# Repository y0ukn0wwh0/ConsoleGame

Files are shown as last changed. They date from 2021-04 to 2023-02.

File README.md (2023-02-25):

# Portable Gaming Console

This repository contains the development process of a portable gaming console based on Arduino, as well as 'DUNG!', a game made with the Arduboy library.
The following paragraphs detail the steps to the building of the console, the game installation and a brief description of it.

## Console Assembly

The following components are used:
- Arduino Nano
- 3 PTS636 switches, 2.5mm height
- MSK12C01-07 slide switch
- 601730 battery, 250mAh, 6*17*30mm dimensions
- TP4056 charging module
- 5kΩ SMD resistor
- i2c OLED screen, 0.96 inches, with the ssd1306 chip
- 5V buzzer, 12mm diameter
- 2 headers, 15 pins each (Arduino Nano)
- Our custom PCB (you can download the files [here](/Console/pcb_dev.zip) and upload them to EasyEDA)

Before welding the components to the PCB it is necessary to switch the charging module resisor to the 5kΩ one.

Having acquired all the required components one can procees with their welding to the PCB following the [schematic](/Console/schematic.png). The following welding order is advised:
1. Charging module
2. Bottom header
3. Buzzer
4. Screen
5. Sliding switch
6. Top header
7. 3 switches
8. Battery



With all the components in place, the board can be set in the box.

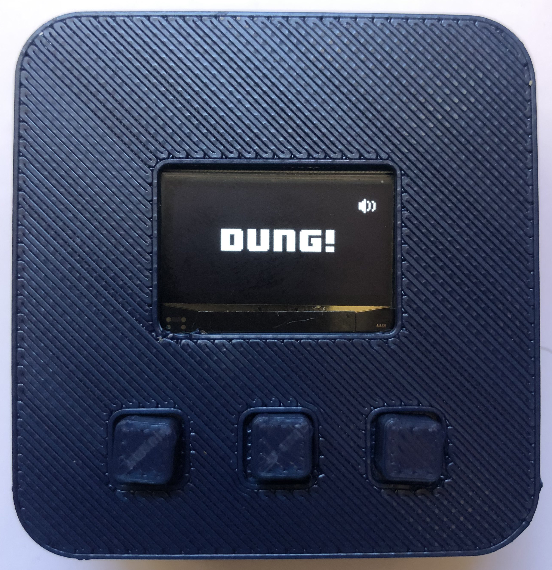
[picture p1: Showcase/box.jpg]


## Alternative to the PCB welding
If one wants a simple setup, the assembly can be done on a breadboard. In this case the only components needed are the Arduino, switches, screen and buzzer. These can be connected to the Arduino pins following the image:

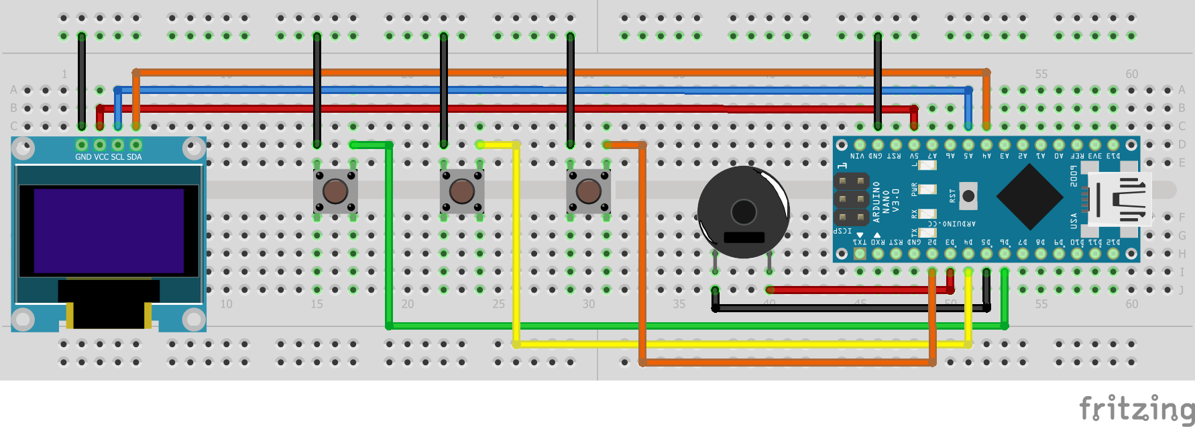
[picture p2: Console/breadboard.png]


## Game
To install the game, the libraries available in the ... folder are necessary. These were obtained from the following repositories:
- [Arduboy2](https://github.com/MLXXXp/Arduboy2)
- [ArduboyTones](https://github.com/MLXXXp/ArduboyTones)
- [ArdBitmap](https://github.com/igvina/ArdBitmap)

The versions available in this repository were slightly altered due to some needed changes like the modification of the button pins.

These libraries are then placed in the correct directory so that the Arduino IDE imports them (generally 'C:\Program Files (x86)\Arduino\libraries').
After this you can simply upload the [game.ino](/Game/game/game.ino) file to the Arduino with the [sprites.c](/Game/game/sprites.c) file in the same folder. The installation is now complete.

### Mechanics
The game has various rounds each containing various levels. The number of levels in each round is increased as the player progresses. The objective is simply to complete as most levels as you can.

In each level, enemies launch projectiles in the direction of the player. In turn, the player has to reflect them by pressing the corresponding button in the right rythm.
Beyond the enemies getting stronger as the game moves forward, at the final level of each round a boss enemy shows up, making the progression more difficult.

At the beginning of each attempt, the following characters are offered as a choice to the player:
| | Warrior | Archer  | Mage |
| --- | --- | --- | --- |
| **Health** | 6 | 4 | 2 |
| **Attack** | 2 | 3 | 4 |

By successfully reflecting enemy projectiles the player wins 'special points'. After accumulating 6 of these points, the player can use the character's special ability:
- **Warrior**: Creates a shield that blocks an enemy projectile.
- **Archer**: Shoots an arrow that drags enemy projectiles in it's direction. In case it hits an enemy directly it inflicts twice the damage.
- **Mage**: Shoots a projectile that heals 1 health point if it hits an enemy. If it doesn't, the mage is unable to attack for 2 seconds. 

There are also various items given to the player randomly after a finished round. These items can be:
- **Weapons**: Add attack damage to the player. Weapons give more damage depending on their level.
- **Gems**: There are several types of gems and they duplicate the damage the player inflicts if they correspond to the type of enemy.
- **Potions**: Heals 1 health point when used.
The player can only hold two items but they can be switched if another one is found. Note that the item that is switched out is lost.

The following image showcases the different bosses correpondent to the enemy/gem types in this order:
- Swamp
- Undead
- Ancient
- Fire
- Forest
- Normal


### Controls
The console's three buttons have the following functions:
| | A Button | B Button | C Button |
| --- | --- | --- | --- |
| **Menus** | Move to the left | Select/Confirm | Move to the right/Return |
| **Game**  | Reflect projectiles | Use potion | Use special attack |

### Interface
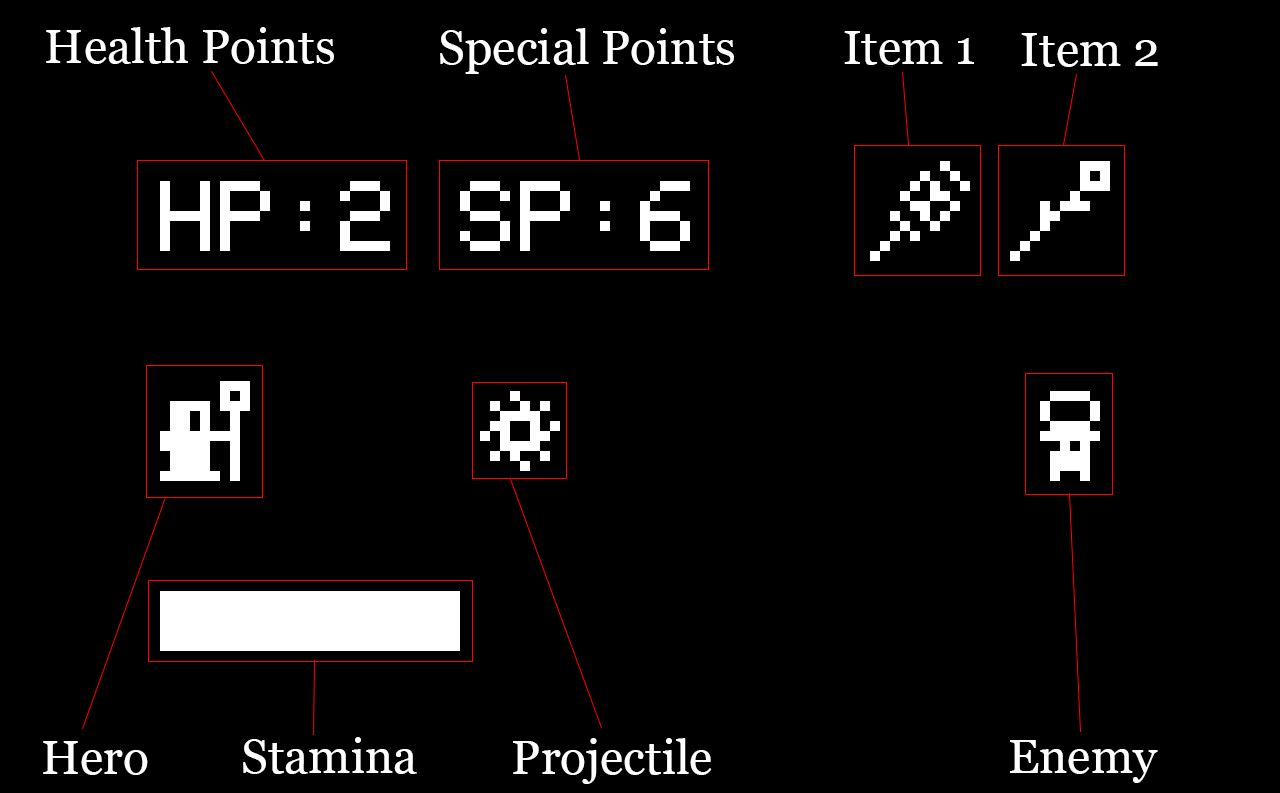
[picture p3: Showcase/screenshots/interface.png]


### Screens
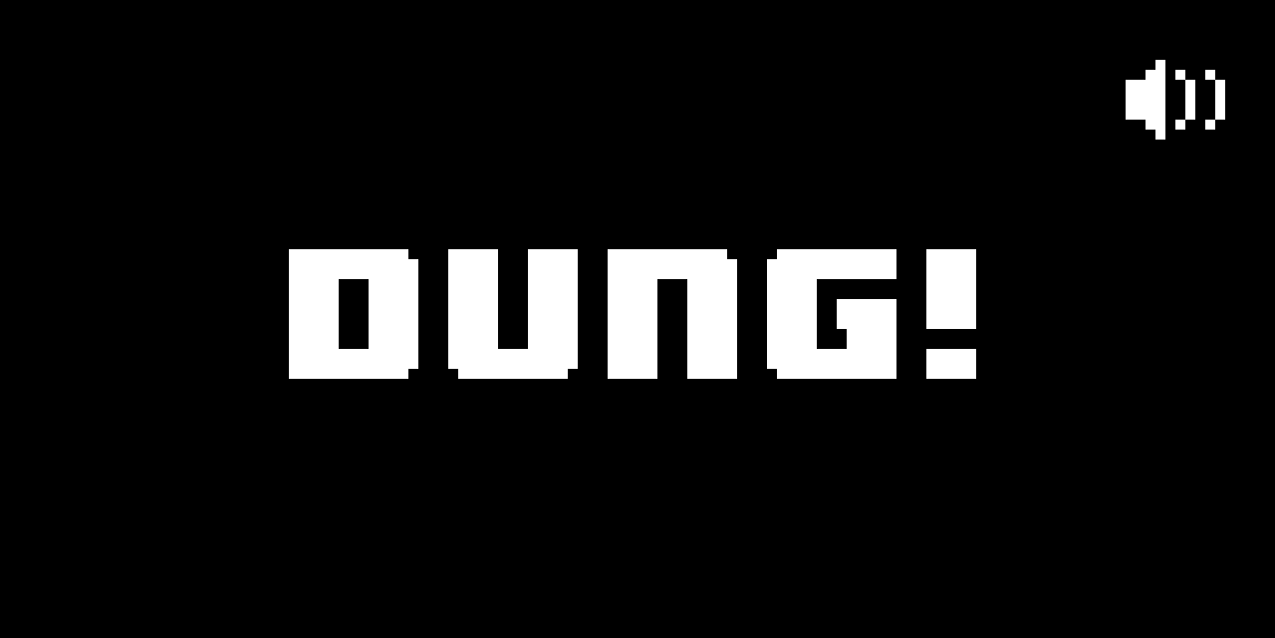
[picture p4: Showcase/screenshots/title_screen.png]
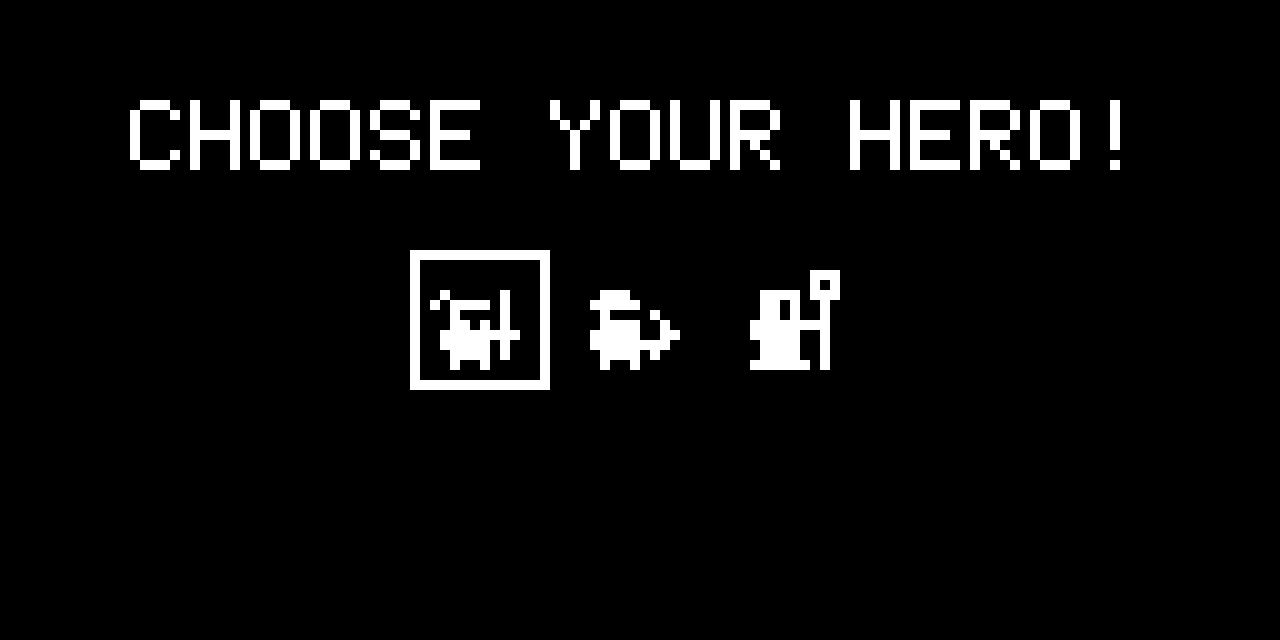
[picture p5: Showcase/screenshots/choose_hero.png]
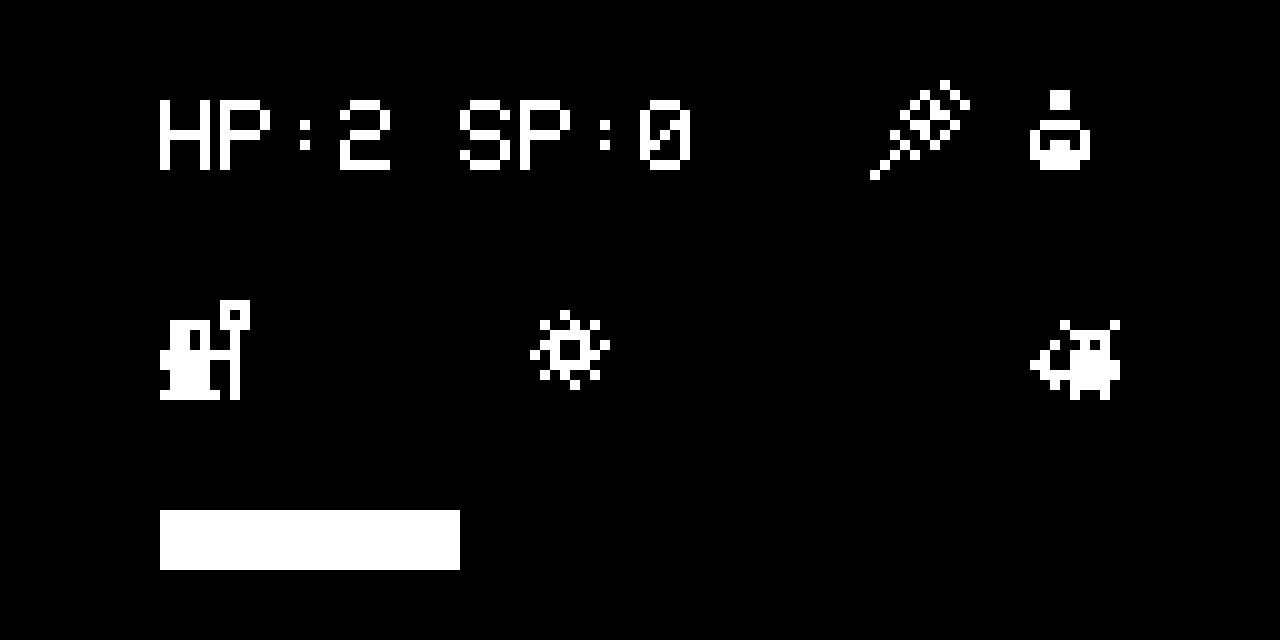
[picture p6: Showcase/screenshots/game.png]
    
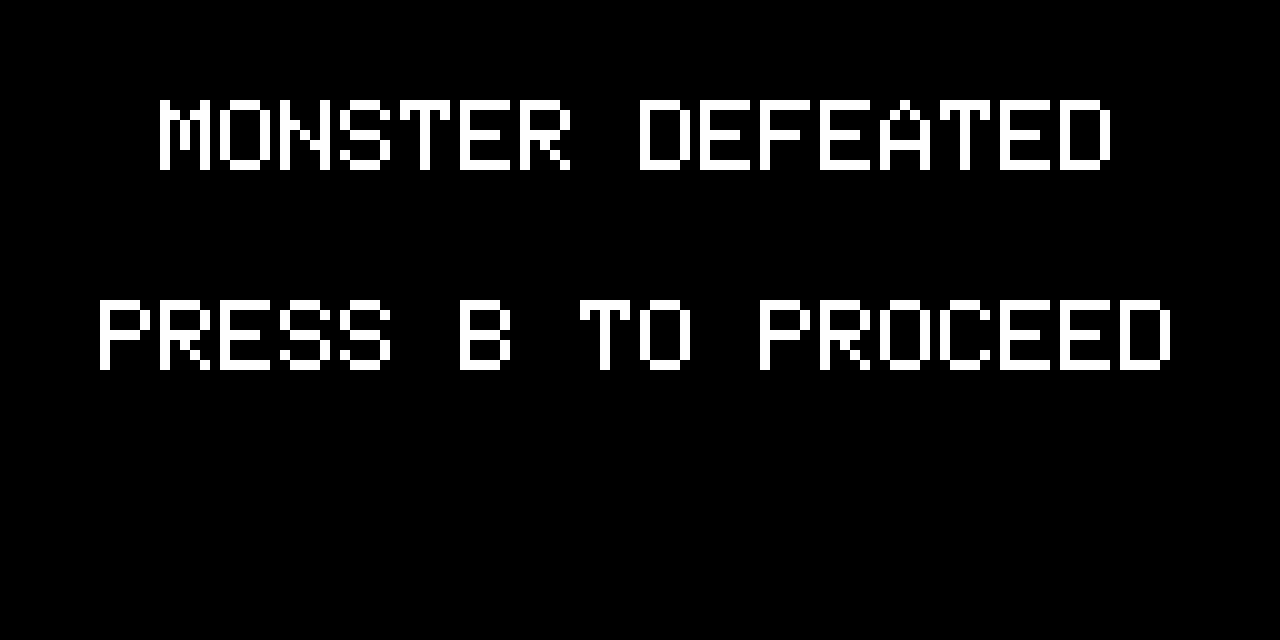
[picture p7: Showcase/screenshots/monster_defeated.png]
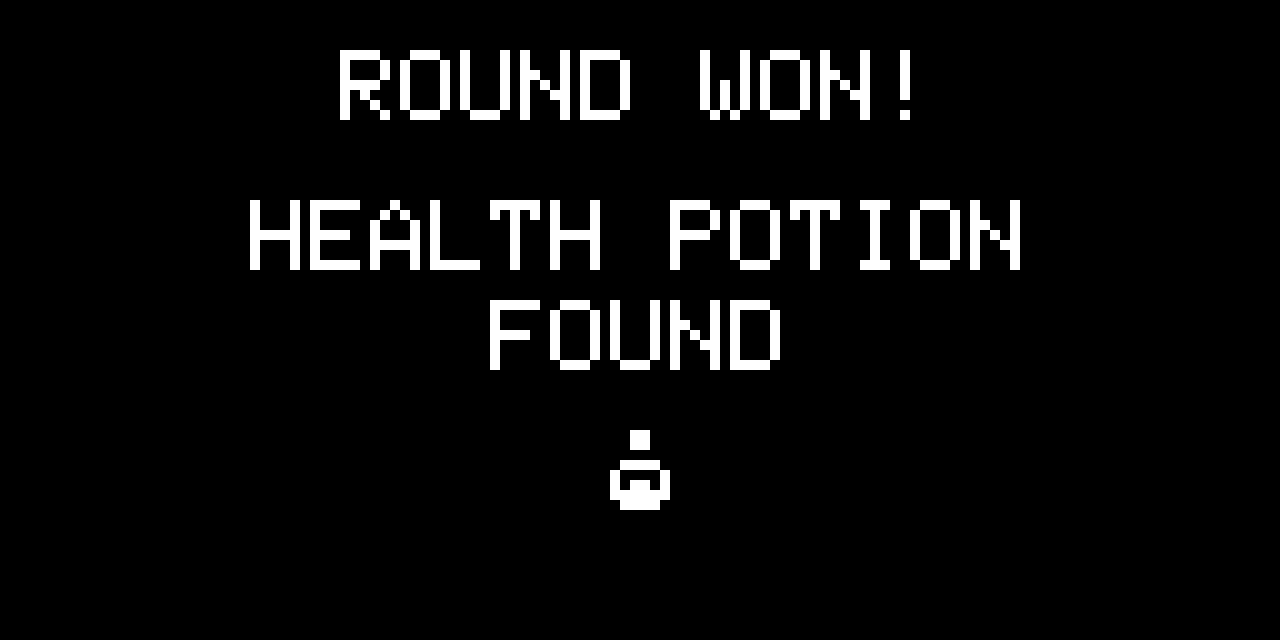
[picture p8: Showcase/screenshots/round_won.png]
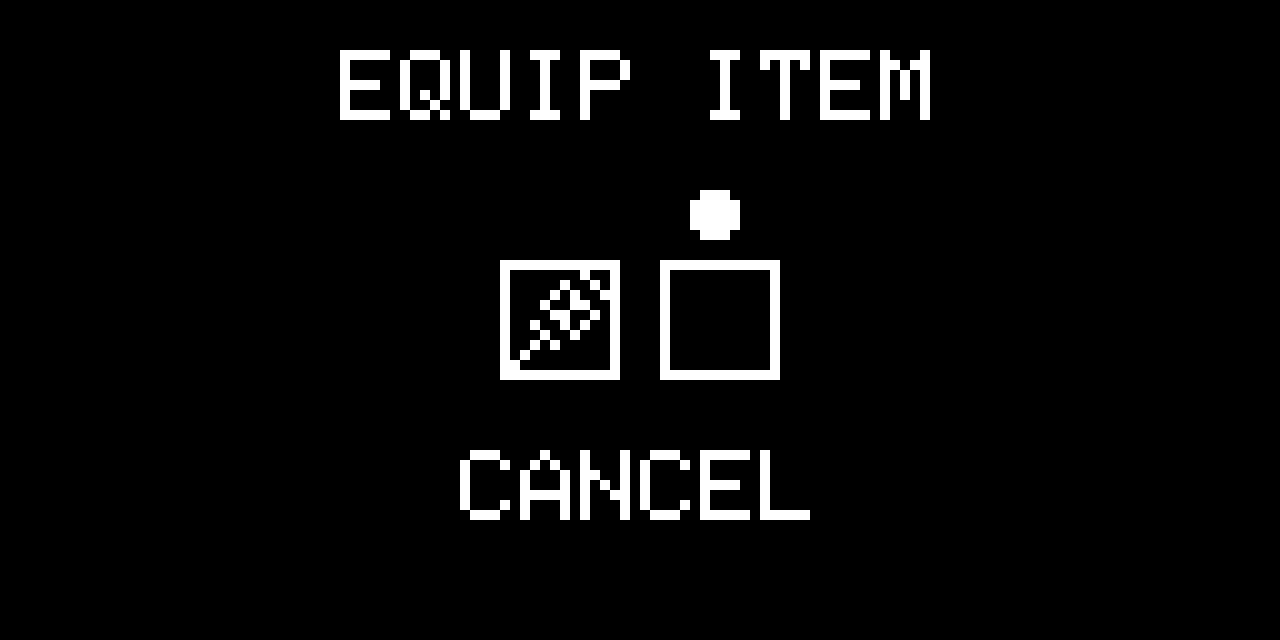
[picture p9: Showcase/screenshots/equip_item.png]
    
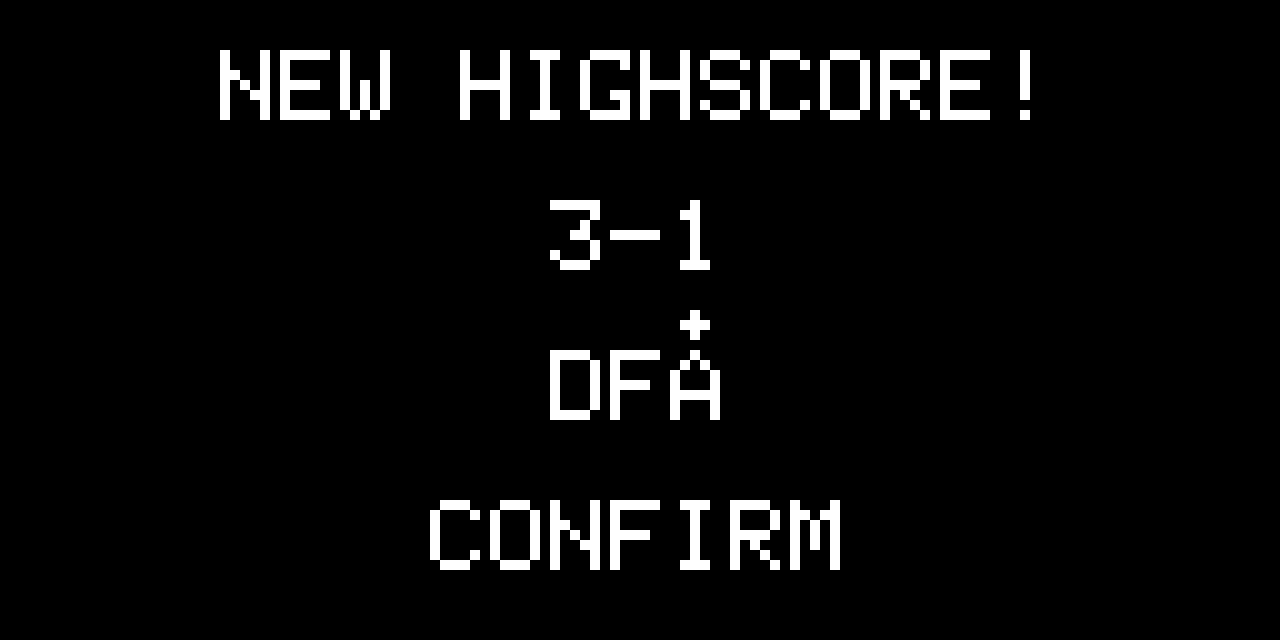
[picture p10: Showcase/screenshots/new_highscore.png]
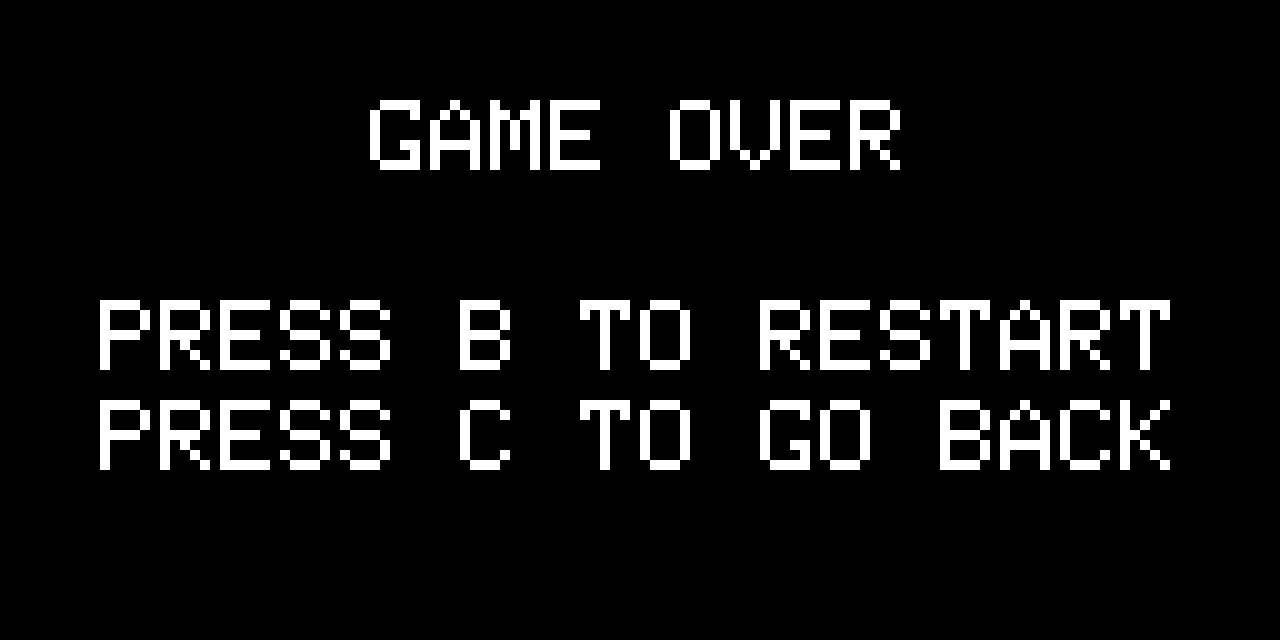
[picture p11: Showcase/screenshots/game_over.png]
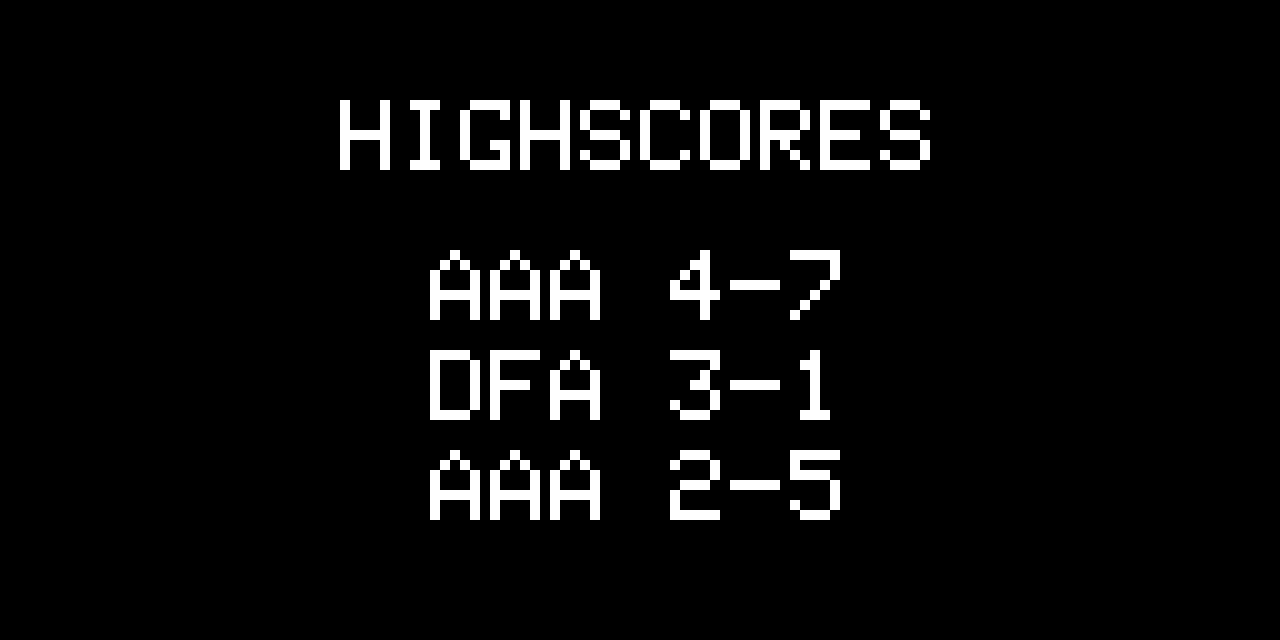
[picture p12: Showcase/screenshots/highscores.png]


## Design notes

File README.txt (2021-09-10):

## Consola de jogo portátil

Este repositório contem o processo de desenvlvimento de uma consola portátil baseada em Arduino, assim como um jogo feito com a biblioteca Arduboy, o DUNG!.
A seguir estão os passos para a construção da mesma assim como a instalação do jogo.

### Consola

São usados os seguintes componentes:
- Arduino Nano
- 3 interruptores PTS636 de 2.5mm de altura
- Interruptor deslizante MSK12C01-07
- Bateria 601730 de 250mAh com dimensões 6*17*30mm
- Módulo de carregamento TP4056
- Resistência SMD de 5kΩ 
- Ecrã OLED i2c de 0.96 polegadas com o chip ssd1306
- Buzzer de 5V, 12mm de diâmetro
- 2 headers cada um com capacidade para 15 pinos (do Arduino Nano)
- O nosso PCB

Antes de se soldar os componentes ao PCB é necessário trocar a resistência do módulo de carregamento para a desejada de 5kΩ.

Tendo todos os componentes prontos é feita agora a soldagem dos mesmos ao PCB. Foi seguida a seguinte ordem de soldagem:
1. Módulo de carregamento
2. Header de baixo
3. Buzzer
4. Ecrã
5. Interruptor deslizante
6. Header de cima
7. 3 interruptores
8. Bateria

A placa fica então com o seguinte aspeto:

Assim a placa eletrónica pode agora ser inserida na caixa desenhada para a consola. Sendo este o resultado final:

### Jogo
Para a instalação do jogo são necessárias as bibliotecas disponíveis na pasta 03_Implementacao. Estas foram obtidas dos seguintes repositórios:
- [Arduboy2](https://github.com/MLXXXp/Arduboy2)
- [ArduboyTones](https://github.com/MLXXXp/ArduboyTones)
- [ArdBitmap](https://github.com/igvina/ArdBitmap)
As versões aqui disponíveis estão ligeiramente diferentes devido a algumas mudanças necessárias como a alteração dos pinos dos botões.

As bibliotecas são então postas na respetiva diretoria para que o Arduino IDE as importe (geralmente C:\Program Files (x86)\Arduino\libraries).
Após isto basta fazer upload do ficheiro game.ino com o ficheiro sprites.c (na pasta 03_Implementacao) para o Arduino. Fica assim a instalção completa.

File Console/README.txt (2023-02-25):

This folder holds the schematics of the eletronic circuit and the pcb as well as the breadboard assembly. The pcb development files exported from EasyEDA are also here inside the 'pcb_dev.zip' file.
In the 'console box' folder are all the files of the box design made in SolidWorks, along with a PNG image showcasing the box model.

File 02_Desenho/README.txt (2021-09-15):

Nesta pasta está o documento de design do jogo desenvolvido em paralelo com o projeto.
Estão também as esquemáticas do circuito, do pcb e montagem numa breadboard.
Na pasta 'caixa' estão todos os ficheiros de desenho da caixa desenvolvidos no SolidWorks, assim como uma imagem PNG.

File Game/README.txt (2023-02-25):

The 'Arduino' folder contains the libraries used in the game development with our changes made.
The 'game' folder contains the main game files:
	- 'game.ino' is the main code with the game mechanics.
	- The file 'sprites.c' has all the graphics used in the game in 'bitmap' format.
	- The python file 'arduboy_screen.py' is used to mirror the game to a computer screen. This was mostly used to take screenshots.

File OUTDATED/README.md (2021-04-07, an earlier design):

# Project

Our goal is to create an arduino-powered mini console that plays a virtual pet game, also developed by the team.
In this current phase of development we have established the following thematics:
- PCB main board developed by the team, to give the console a shape and to connect the following components:

	- Arduino Nano;
	- 0.96" OLED screen;
	- 6 buttons;
	- Buzzer;
	- TP4056 micro-usb lithium battery charging module;
	- 90mAh LiPo battery;
	- RC-522 RFID module;

- Develop the pet's statistics by doing either idle actions or interacting with the pet through minigames;

	- Feeding minigame, where the player has to control his pet to catch food falling from the top of the screen;
	- Exercise minigame, where the player has to hit a sequence of keys presented to him, in it's exact order;
	- Adventure minigame, where the pet goes on an adventure and the console is set idle, until the pet comes back;

- RFID implementation (sensor and tag) to randomize events or let players fight which eachother's pets;

The concepts presented here are still rough ideas, they can and will be changed in the future, to match the team's ideas.

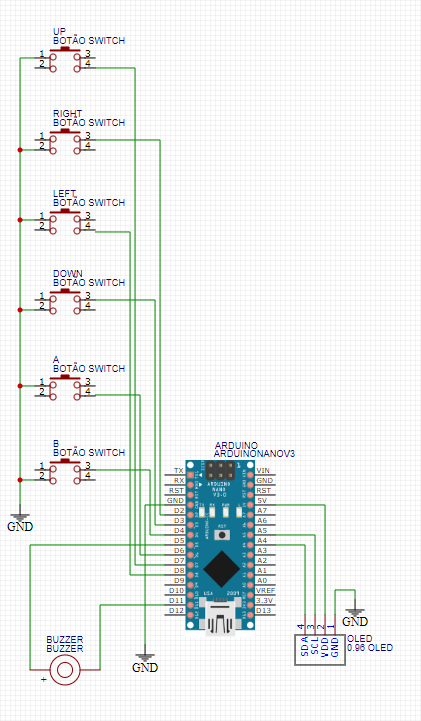
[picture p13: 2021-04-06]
images/schematic.png

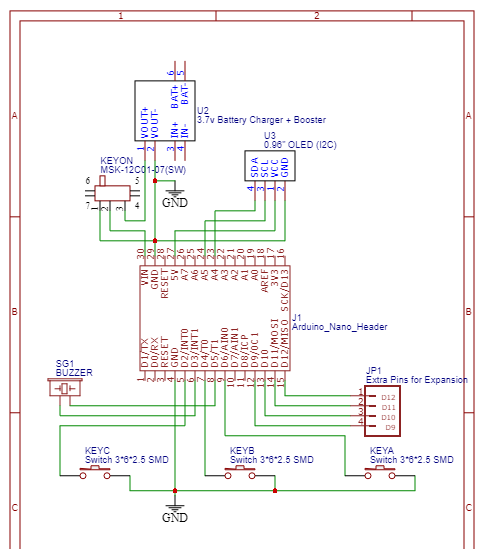
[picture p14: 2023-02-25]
Console/schematic.png

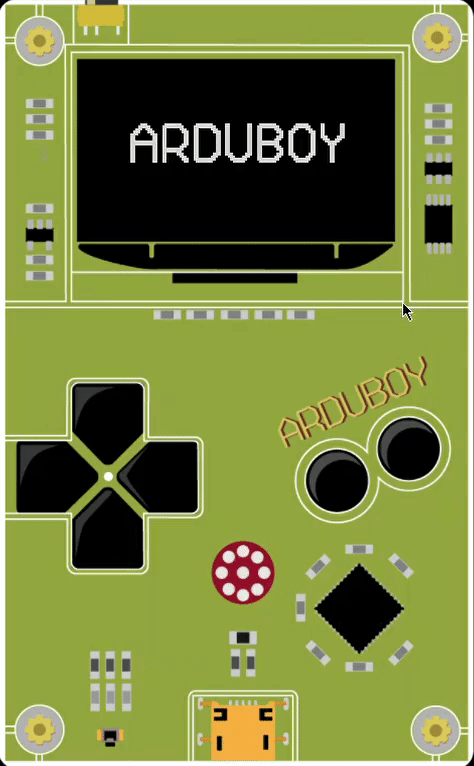
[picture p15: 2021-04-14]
images/match.gif

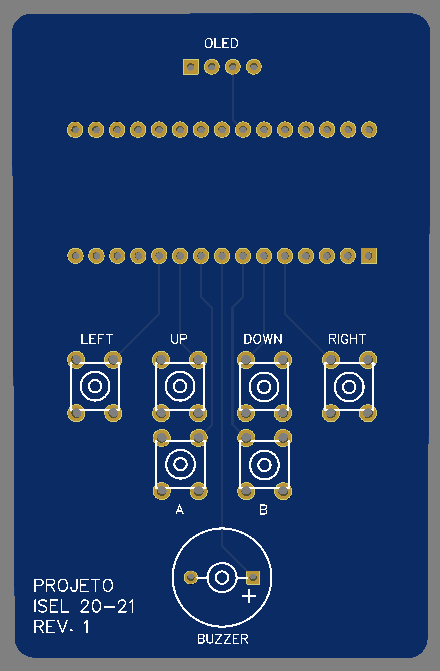
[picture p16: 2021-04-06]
images/pcb_3d_front.png

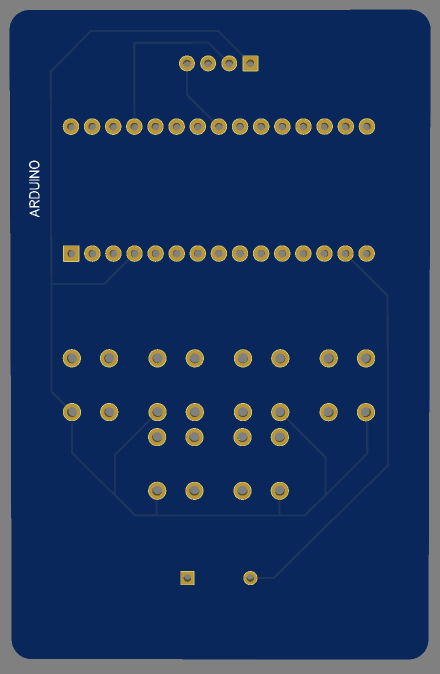
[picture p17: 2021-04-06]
images/pcb_3d_back.png

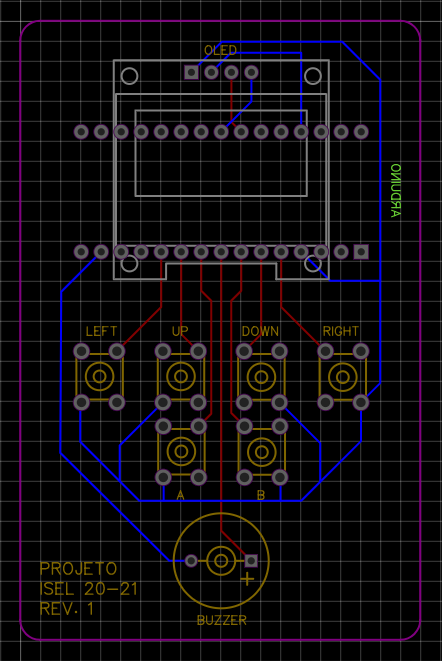
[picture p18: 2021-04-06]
images/pcb.png

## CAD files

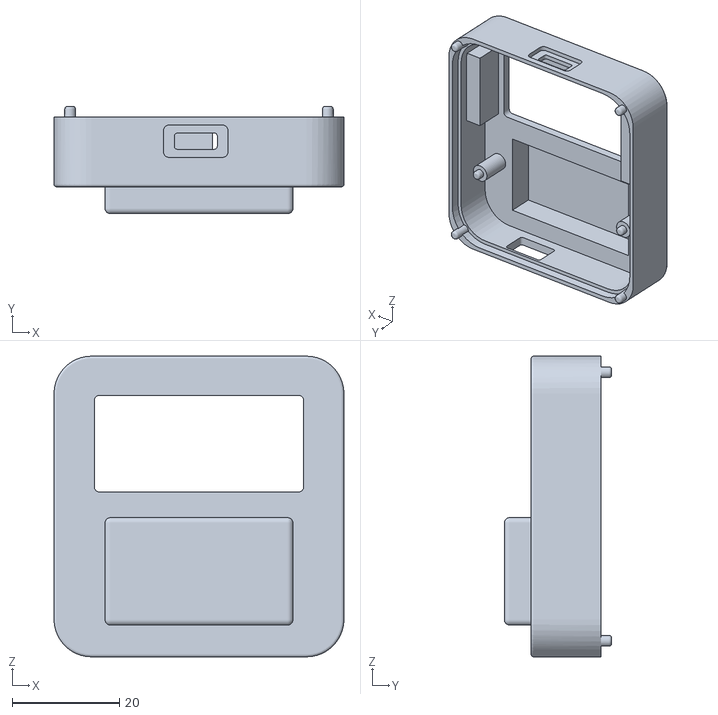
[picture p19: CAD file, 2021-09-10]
Console/console box/AssemblyV2 - PartBottom-2.STL
54.0 x 20.0 x 56.0

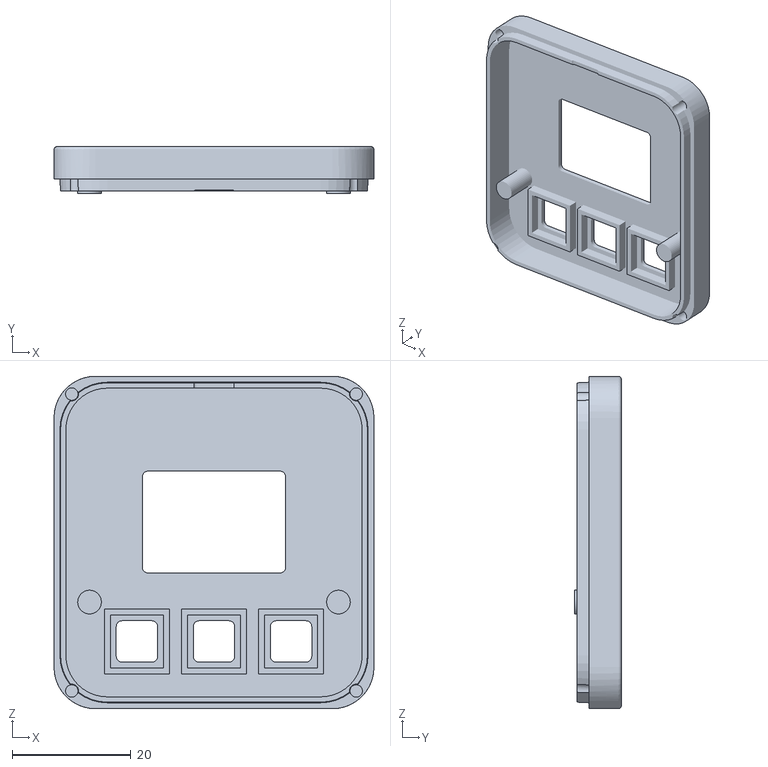
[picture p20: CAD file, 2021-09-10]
Console/console box/AssemblyV2 - PartTop-1.STL
54.0 x 7.90 x 56.1

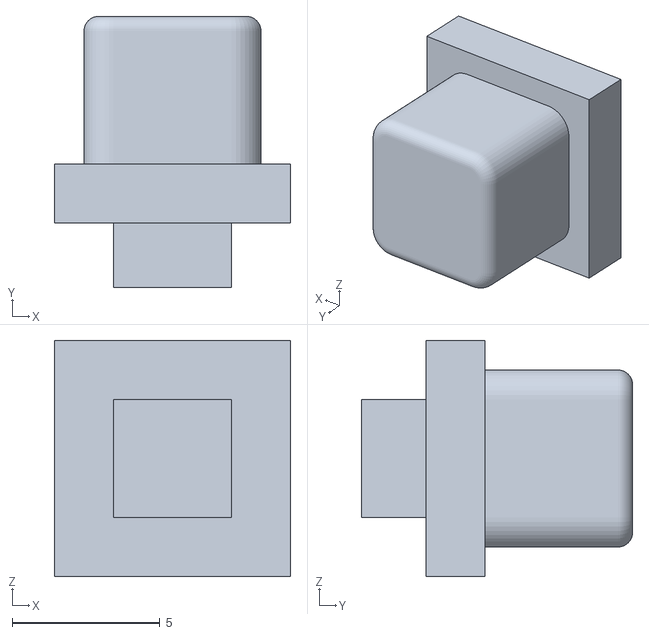
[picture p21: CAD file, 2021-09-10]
Console/console box/AssemblyV2 - Button-1.STL
8.00 x 9.20 x 8.00

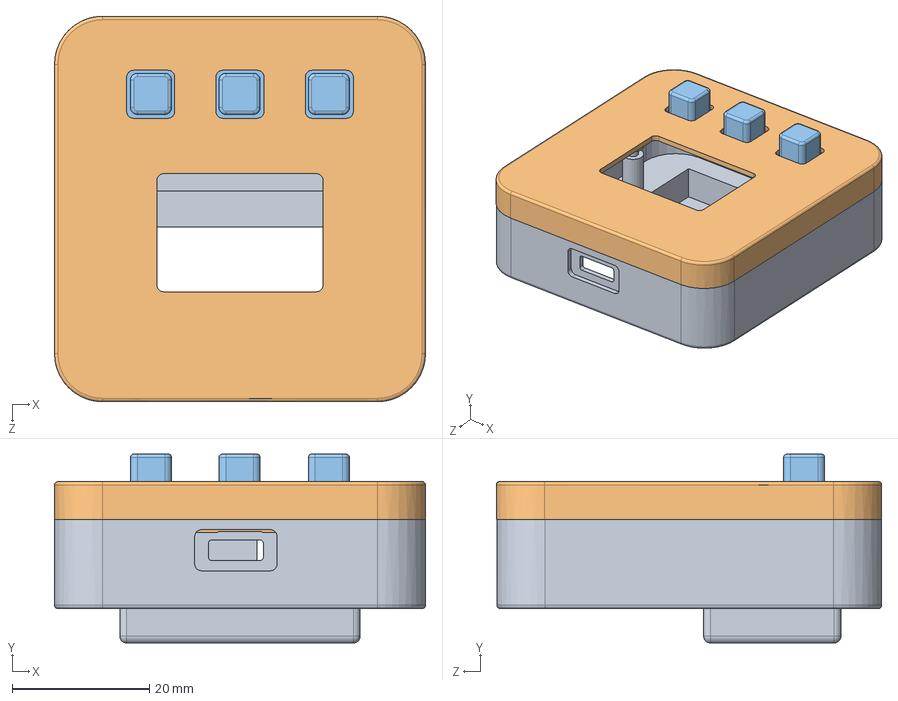
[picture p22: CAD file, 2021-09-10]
Console/console box/Assembly.SLDASM
54.0 x 27.5 x 56.1 mm
PartBottom
PartTop
Button x 3

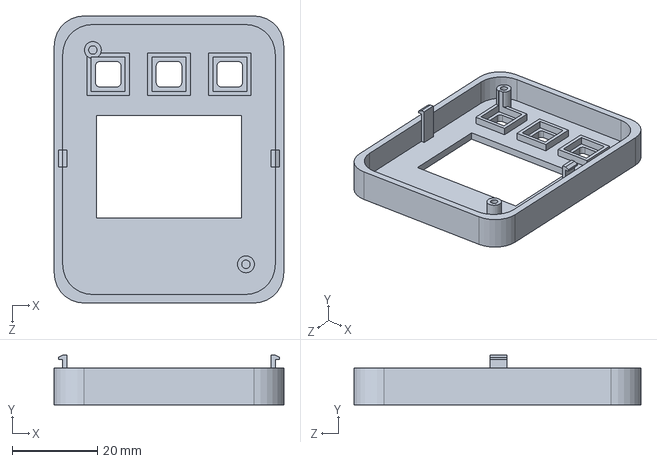
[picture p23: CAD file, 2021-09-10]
Console/console box/PartTop.SLDPRT
54.0 x 11.7 x 67.5 mm

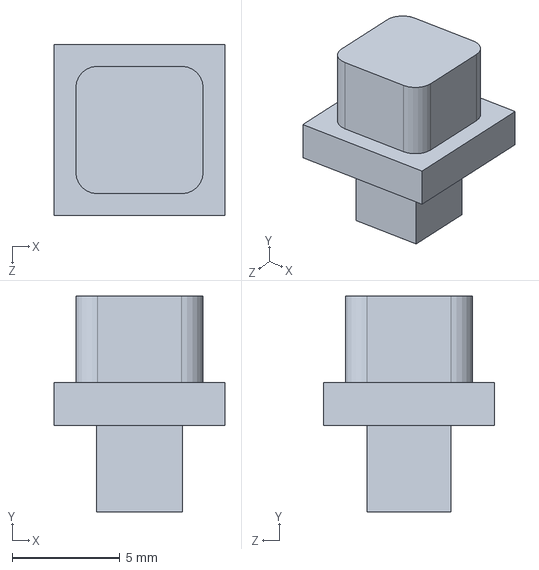
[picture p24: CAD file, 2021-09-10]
Console/console box/Button.SLDPRT
7.90 x 10.0 x 7.90 mm

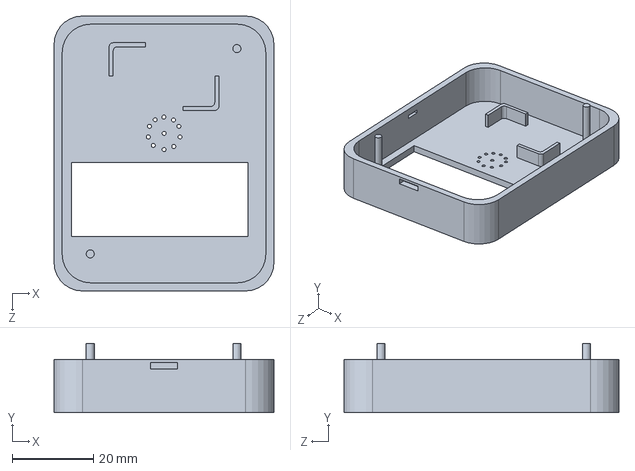
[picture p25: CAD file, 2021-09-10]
Console/console box/PartBottom.SLDPRT
54.0 x 17.0 x 67.5 mm

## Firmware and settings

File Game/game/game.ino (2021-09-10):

#include <Arduboy2.h>
#include <ArduboyTones.h>
#include <EEPROM.h>
#include "sprites.c"

const uint16_t score[] PROGMEM = {
 NOTE_C5,205, NOTE_REST,205, NOTE_C5,205, NOTE_G5,205, NOTE_F5,205, NOTE_REST,205, NOTE_E5,205, NOTE_REST,205,
 NOTE_C5,205, NOTE_REST,205, NOTE_C5,205, NOTE_G5,205, NOTE_F5,205, NOTE_REST,205, NOTE_E5,205, NOTE_REST,205,
 NOTE_C5,205, NOTE_REST,1027, NOTE_E5,205, NOTE_REST,205, NOTE_C5,205, NOTE_REST,1027, NOTE_E5,205, NOTE_REST,205,
 TONES_REPEAT
};

#define HEROX 16                                                    //Hero position
#define FLOOR_LEVEL 40                                              //The bottom edge of where the heroes and monsters are drawn
#define BASIC_ENEMY_LEFT arduboy.width()-26                         //Left side of the basic enemies aka where the projectiles are spawned
#define BOSS_LEFT arduboy.width()-36                                //Left side of the bosses
#define REQUIRED_STAMINA 30                                         //The stamina the hero requires to attack       
#define REQUIRED_SPECIAL_POINTS 6                                   //Required special points to use hero's special 
#define REQUIRED_RECOVER_TIME 2000                                  //Time for the mage to recover from a failed spell
#define FIRST_ITEM_X arduboy.width()/2 - 9                          //X position of the first slot in the equip menu
#define SECOND_ITEM_X arduboy.width()/2 + 7                         //X position of the second slot in the equip menu
const String alphabet = "ABCDEFGHIJKLMNOPQRSTUVXYZ";                //Alphabet to insert the player's name when he has a new highscore

Arduboy2 arduboy;
ArduboyTones sound(arduboy.audio.enabled);
enum screen {start, choose, game, over, won, roundOver, equipItem, highscore}; //All the different screens in the game
screen sc = start;                                                  //Current screen
enum heroType {s, a, m};                                            //Types of heroes - Swordsman, Archer, Mage
byte heroChoiceX = 41;                                              //Used to determine where the selection rectangle in the choice menu is drawn
byte level, gameRound;                                              //Game level and round
uint8_t *enemy;                                                     //Enemy to draw
float projectileX, projectileSpeed;                                 //Enemy projectile's position and it's speed
bool goToPlayer;                                                    //Used to know whether the projectile goes towards the player
unsigned long projectileRecharge;                                   //Used to know when to spawn another projectile if needed
unsigned long recoverTime;                                          //Used to know if the recover time for the mage has passed after missing a spell
byte currentStamina;                                                //Current amount of stamina that the player has
byte maxEnemyHealth, enemyHealth;                                   //Enemies max and current health
byte enemyType;                                                     //Enemy type (1-Normal, 2-Forest, 3-Fire, 4-Swamp, 5-Ancient, 6-Undead)
byte enemyLeft;                                                     //Left side of the enemy, whter it be basic or boss
bool bossLevel, bossDefeated;                                       //Used to know if the level is a boss one and if it was defeated
uint8_t* rewardedItem;                                              //Rewarded item after a boss
String rewardName;                                                  //Rewarded item's name
bool itemFound;                                                     //Used to know if an item was found after the boss round
byte itemChoiceX = FIRST_ITEM_X;                                    //Used in the equip item screen to cyle through the item slots
byte letter1=0, letter2=0, letter3=0;                               //Letters of the name to register after a highscore. These are indexes of the alphabet string
byte letterChoiceX = arduboy.width()/2 - 7;                         //Used to cycle through the letters in the highscore screen
byte highscoreAddr;                                                 //EEPROM address to right a new highscore
bool showHighscore;                                                 //Tells the start screen to show the highscores or not
bool playAudio = true;                                              //Should the console play audio or not

//Animation stuff
#define ARDBITMAP_SBUF arduboy.getBuffer()                          //Screen buffer pointer expression (used in the ArdBitmap library)
#include <ArdBitmap.h>                                              //ArdBitmap - Library to edit sprites
ArdBitmap<WIDTH, HEIGHT> ardbitmap;
byte frame;                                                         //Used to draw the projectiles in the drawRotatedProjectile function
long changeFrameTime;                                               //Know when to change the frame
float logoSize;                                                     //Used in the resize animation for the logo in the start screen

//Used to know when is time to write the screen buffer to serial.
//unsigned long timeSerial;

//Hero classes
class Hero{
  public:
    byte maxHealth, health, basicAttack, attack, arrowX, spellX, specialPoints;
    uint8_t* weapon1; uint8_t* weapon2; uint8_t* weapon3; uint8_t* weapon4; uint8_t* weapon5;
    uint8_t* item1; uint8_t* item2;
    boolean usedSpecial = false, item1Def = false, item2Def = false;
    virtual void draw();
    virtual void useSpecial();
    virtual heroType getType();
};

//The Swordsman has a large amount of health, but does less damage 
//His special is a shield that protects him from the enemy one time
class Swordsman : public Hero{
  public:
    Swordsman(){
      maxHealth = 6; health = maxHealth; basicAttack = 2; attack = basicAttack;
      weapon1 = sword1; weapon2 = sword2; weapon3 = sword3; weapon4 = sword4; weapon5 = sword5;
    }
    virtual void draw(){
      arduboy.drawBitmap(HEROX,FLOOR_LEVEL-10, swordsman, 10, 10);
      if(usedSpecial)
        arduboy.drawCircle(HEROX+4, FLOOR_LEVEL-5, 7);
    }

    virtual void useSpecial(){
       if(!usedSpecial && specialPoints == REQUIRED_SPECIAL_POINTS){
        usedSpecial = true;
        specialPoints = 0;
      }
    }

    virtual heroType getType(){
      return s;
    }
};

//The Archer is has a decent amount of health and does a bit more damage than the Swordsman
//His special is an arrow that drags the enemy projectiles towards them but deals more damage if it doesn't
class Archer : public Hero{
  public:
    Archer(){
      maxHealth = 4; health = maxHealth; basicAttack = 3; attack = basicAttack;
      weapon1 = bow1; weapon2 = bow2; weapon3 = bow3; weapon4 = bow4; weapon5 = bow5;
    }
    virtual void draw(){
      arduboy.drawBitmap(HEROX,FLOOR_LEVEL-10, archer, 10, 10);
      if(usedSpecial){
        arduboy.drawBitmap(arrowX,FLOOR_LEVEL-5, arrow, 10, 3);
        arrowX+=2;

        //If arrow directly hits the enemy it does double the damage
        if(arrowX+10 >= enemyLeft){
          usedSpecial = false;
          arrowX = 0;
          (attack*2 > enemyHealth) ? enemyHealth = 0 : enemyHealth -= attack*2;
          if(playAudio)sound.tone(600,200);
        }
      }
    }
    virtual void useSpecial(){
      if(!usedSpecial && specialPoints == REQUIRED_SPECIAL_POINTS){
        arrowX = HEROX;
        usedSpecial = true;
        specialPoints = 0;
      }
    }
    virtual heroType getType(){
      return a;
    }
};

//The Mage is very fragile but does more damage than the other classes
//His special fires a spell that recovers 1 health point if it hits the enemy
//If it hits a projectile, it prevents the mage from doing anything for 2 seconds
class Mage : public Hero{
  public:
    Mage(){
      maxHealth = 2; health = maxHealth; basicAttack = 4; attack = basicAttack;
      weapon1 = staff1; weapon2 = staff2; weapon3 = staff3; weapon4 = staff4; weapon5 = staff5;
    }
    virtual void draw(){
      arduboy.drawBitmap(HEROX,FLOOR_LEVEL-10, mage, 10, 10);
      if(usedSpecial){
        arduboy.drawBitmap(spellX,FLOOR_LEVEL-9, spell, 10, 3);
        spellX+=2;

        //Spell recovers health if it hits the enemy
        if(spellX+10 >= enemyLeft){
          usedSpecial = false;
          spellX = 0;
          (attack > enemyHealth) ? enemyHealth = 0 : enemyHealth -= attack;
          if(playAudio)sound.tone(600,200);
          if(health < maxHealth)
            health++;
        }
      }
    }
    virtual void useSpecial(){
     if(!usedSpecial && specialPoints == REQUIRED_SPECIAL_POINTS){
        spellX = HEROX;
        usedSpecial = true;
        specialPoints = 0;
      }
    }
    virtual heroType getType(){
      return m;
    }
};

Hero *hero;

void setup(){
  //Serial.begin(250000);
  arduboy.beginDoFirst();
  arduboy.initRandomSeed();
  sound.tones(score);
}

void loop(){
  if (!(arduboy.nextFrame()))
    return;

  arduboy.clear();
  arduboy.pollButtons();

  switch(sc){
    case start:
      if(arduboy.justPressed(A_BUTTON)){
        playAudio = !playAudio;
        if(playAudio)sound.tones(score);
        else sound.noTone();
          
      }
      if(arduboy.justPressed(B_BUTTON)){
        showHighscore = !showHighscore;
      }

      //If the player wants to see the highscores, read the corresponding addresses in the EEPROM
      //In order: round, level, first letter of the name to register, second letter, third letter
      if(showHighscore){
        printCentered(10, F("HIGHSCORES"));
        byte firstAddr = EEPROM_STORAGE_SPACE_START;
        byte hsX = 25;
        for(byte i = firstAddr; i <= firstAddr + 10; i += 5){
          byte eepromRound = EEPROM.read(i);
          if(eepromRound != 255){
            byte eepromLevel = EEPROM.read(i+1);
            byte firstLetter = EEPROM.read(i+2);
            byte secondLetter = EEPROM.read(i+3);
            byte thirdLetter = EEPROM.read(i+4);
            String hsName = String(char(firstLetter))+String(char(secondLetter))+String(char(thirdLetter))+" "+String(eepromRound)+"-"+String(eepromLevel);
            printCentered(hsX, hsName);
            hsX += 10;
          }
        }
      }else{
        //Increase logo size to full, to make a little animation
        if(logoSize < 1)
          logoSize += 0.01;
        ardbitmap.drawBitmapResized(arduboy.width()/2 - (73*logoSize)/2, arduboy.height()/2 - (17*logoSize)/2, logo, 73, 17, WHITE, ALIGN_NONE, MIRROR_NONE, logoSize);

        if(playAudio)
          arduboy.drawBitmap(arduboy.width()-15, 5, audio, 10, 10);
        
        if(arduboy.justPressed(DOWN_BUTTON)){
          sc = choose;
          sound.noTone();
        }
      }
      
      break;
      
    case choose:
      //Draw possible selections
      printCentered(10, F("CHOOSE YOUR HERO!"));
      arduboy.drawBitmap(43, arduboy.height()/2-5, swordsman, 10, 10);
      arduboy.drawBitmap(59, arduboy.height()/2-5, archer, 10, 10);
      arduboy.drawBitmap(75, arduboy.height()/2-5, mage, 10, 10);
      arduboy.drawRect(heroChoiceX, arduboy.height()/2 - 7, 14, 14);

      //Cycle the selection through the different heroes
      //Right
      if(arduboy.justPressed(B_BUTTON)){
        if(playAudio)sound.tone(4000,100);
        if(heroChoiceX < 73)heroChoiceX += 16;
        else heroChoiceX = 41;
      }
      //Left
      if(arduboy.justPressed(A_BUTTON)){
        if(playAudio)sound.tone(4000,100);
        if(heroChoiceX > 41)heroChoiceX -= 16;
        else heroChoiceX = 73;
      }
      //Confirm
      if(arduboy.justPressed(DOWN_BUTTON)){
        if(playAudio)sound.tone(4000,100,4500,100,5000,100);
        switch(heroChoiceX){
          case 41:
            hero = new Swordsman;
            break;
          case 57:
            hero = new Archer;
            break;
          case 73:
            hero = new Mage;
            break;
        }
        reset();
        sc = game;
      }
      break;

    case game:
      //Check if the enemy in this level is a boss
      if(bossLevel){
        enemyLeft = BOSS_LEFT;
        arduboy.drawBitmap(BOSS_LEFT, FLOOR_LEVEL-20, enemy, 20, 20);
      }else{
        enemyLeft = BASIC_ENEMY_LEFT;
        arduboy.drawBitmap(enemyLeft, FLOOR_LEVEL-10, enemy, 10, 10);
      }
    
      //Draw in order: hero, current stamina, health points, special points and items
      hero->draw();
      //arduboy.setCursor(arduboy.width() - 22, 3);
      //arduboy.print(enemyHealth);
      arduboy.fillRect(HEROX, FLOOR_LEVEL + 11, currentStamina, 6);
      arduboy.setCursor(HEROX, 10);
      arduboy.print(F("HP:"));
      arduboy.print(hero->health);
      arduboy.print(F(" SP:"));
      arduboy.print(hero->specialPoints);
      //arduboy.drawRect(arduboy.width() - 42, FLOOR_LEVEL + 6, 12, 12);
      //arduboy.drawRect(arduboy.width() - 28, FLOOR_LEVEL + 6, 12, 12);
      if(hero->item1Def)
        arduboy.drawBitmap(arduboy.width() - 41, 8, hero->item1, 10, 10);
      if(hero->item2Def)
        arduboy.drawBitmap(arduboy.width() - 27, 8, hero->item2, 10, 10);

      //If projectile is not destroyed, move it
      if(projectileX > 0){
        drawProjectile();
        
        //Move the projectile every frame
        if(goToPlayer)
          projectileX-=projectileSpeed;
        else
          projectileX+=projectileSpeed;

        //In case the hero is an archer and he shot his special arrow, the projectile is dragged by the arrow fired
        if(hero->getType() == a && hero->usedSpecial){
          if(projectileX <= hero->arrowX + 10){
            projectileX = hero->arrowX + 10;
            goToPlayer = false;
            if(projectileX+5 >= enemyLeft){
              hero->usedSpecial = false;
              hero->arrowX = 0;
            }
          }
        }

        //If the hero is a mage the spell fired by him destroys the projectile aswell as the spell itself
        //also start the timer for the mage's recovery and for the enemy's projectile
        if(hero->getType() == m && hero->usedSpecial){
          if(projectileX <= hero->spellX + 10 && goToPlayer == true){
            hero->usedSpecial = false;
            hero->spellX = 0;
            projectileX = 0;
            recoverTime = millis();
            projectileRecharge = millis();
            currentStamina = 0;
          }
        }

        //Enemy health depleted if the projectile is going towards the enemy and touches them
        if(projectileX+5 >= enemyLeft && !goToPlayer){
          if(playAudio)sound.tone(600,200);
          (hero->attack > enemyHealth) ? enemyHealth = 0 : enemyHealth -= hero->attack;
          goToPlayer = true;
          projectileX = 0;
          projectileRecharge = millis();
        }
        
      //Spawn another projectile after 0.8 seconds if the first was destroyed
      }else if(millis() - projectileRecharge > 800){
        if(playAudio)sound.tone(500,100);
        projectileX = enemyLeft;
      }

      //If the projectile touches the player it is reflected in case the hero is a swordsman and used the shield
      //else reduce health, and destroy the projectile (by setting its position to 0)
      if(projectileX+5 < HEROX + 8 && projectileX > 0){
        if(hero->getType() == s && hero->usedSpecial){
          goToPlayer = false;
          hero->usedSpecial = false;
          if(playAudio)sound.tone(800,200);
        }else{
          if(bossLevel){
            if(2 > hero->health)hero->health = 0;
            else hero->health-=2;
          }
          else hero->health--;
          projectileX = 0;
          projectileRecharge = millis();
          if(playAudio)sound.tone(100,100);
        }
      }

      //Level won if the enemy has no health left
      if(enemyHealth == 0){
        sc = won;
        if(bossLevel)
          bossDefeated = true;
      }

      //Game over if the player has no health left. Also check for a new highscore
      if(hero->health == 0){
        if(playAudio)sound.tone(300,200,200,200,100,200);
        highscoreAddr = checkForHighscore();
        if(highscoreAddr > 0)
          sc = highscore;
        else
          sc = over;
      }

      //Recharge stamina after it's depleted
      //If the hero is a mage and is still recovering, the stamina does not recharge
      if(currentStamina < REQUIRED_STAMINA){
        if(hero->getType() != m || millis() - recoverTime > REQUIRED_RECOVER_TIME)
          currentStamina++;
      }

      //If the player timed the button press correctly and he has enough stamina, the projectile is reflected
      //also reward the player with a special point
      if(arduboy.justPressed(A_BUTTON) && currentStamina == REQUIRED_STAMINA){
        if(projectileX+5 < HEROX + 16  && projectileX+5 > HEROX + 8 ){
          if(hero->specialPoints < REQUIRED_SPECIAL_POINTS)
            hero->specialPoints++;
          goToPlayer = false;
          if(playAudio)sound.tone(800,200);
        }
        currentStamina = 0;
      }

      //Use hero's special
      if(arduboy.justPressed(B_BUTTON)){
        if(currentStamina == REQUIRED_STAMINA)
          hero->useSpecial();
          if(playAudio)sound.tone(4000,50,2000,50,1000,50);
      }

      //Use health potion if the player has one. Always check slot 1 first
      if(arduboy.justPressed(DOWN_BUTTON)){
        if(hero->health < hero-> maxHealth){
          if(hero->item1Def && hero->item1 == healthPotion){
            hero->health++;
            hero->item1Def = false;
            if(playAudio)sound.tone(1000,200);
          }else if(hero->item2Def && hero->item2 == healthPotion){
            hero->health++;
            hero->item2Def = false;
            if(playAudio)sound.tone(1000,200);
          }
        }
      }
      break;

    case over:
      printCentered(10, F("GAME OVER"));
      printCentered(30, F("PRESS B TO RESTART"));
      printCentered(40, F("PRESS C TO GO BACK"));
      if(arduboy.justPressed(DOWN_BUTTON)){
        reset();
        sc = game;
        if(playAudio)sound.tone(4000,100,4500,100,5000,100);
      }else if(arduboy.justPressed(B_BUTTON)){
        sc = start;
        if(playAudio)sound.tones(score);
      }
      break;
      
    case won:

      //Check if it is a boss level
      bossLevel = (level == gameRound+2);

      if(bossDefeated){
        nextLevel(bossLevel);
      }else{
        printCentered(10, F("MONSTER DEFEATED"));
        printCentered(30, F("PRESS B TO PROCEED"));
  
        if(arduboy.justPressed(DOWN_BUTTON)){
          nextLevel(bossLevel);
          if(playAudio)sound.tone(500,100);
        }
      }
      break;
      
    case roundOver:
    
      //If an item is found go to the equip screen
      printCentered(5, F("ROUND WON!"));
      if(itemFound){
        printCentered(20, rewardName);
        printCentered(30, F("FOUND"));
        arduboy.drawBitmap(arduboy.width()/2 - 5, arduboy.height()/2 + 10, rewardedItem, 10, 10);
        if(arduboy.justPressed(DOWN_BUTTON)){
          sc = equipItem;
          if(playAudio)sound.tone(4000,100);
        }
      }else{
        printCentered(20, F("NOTHING FOUND"));
        printCentered(30, F("THIS TIME"));
        if(arduboy.justPressed(DOWN_BUTTON)){
          sc = game;
          if(playAudio)sound.tone(500,100);
        }
      }
      break;

    case equipItem:

      //Show item slots and equiped items
      printCentered(5, F("EQUIP ITEM"));
      arduboy.drawRect(arduboy.width()/2 - 14, arduboy.height()/2 - 6, 12, 12);
      arduboy.drawRect(arduboy.width()/2 + 2, arduboy.height()/2 - 6, 12, 12);
      if(hero->item1Def)
        arduboy.drawBitmap(arduboy.width()/2 - 13, arduboy.height()/2 - 5, hero->item1, 10, 10);
      if(hero->item2Def)
        arduboy.drawBitmap(arduboy.width()/2 + 3, arduboy.height()/2 - 5, hero->item2, 10, 10);

      printCentered(45, "CANCEL");

      //Draw circle that indicates what is selected. Change y position if the selection is the cancel button.
      if(itemChoiceX == 40)
        arduboy.fillCircle(itemChoiceX, 48, 2);
      else
        arduboy.fillCircle(itemChoiceX, arduboy.height()/2 - 11, 2);

      //Cycle through the options.
      //Left
      if(arduboy.justPressed(A_BUTTON)){
        if(playAudio)sound.tone(4000,100);
        if(itemChoiceX == FIRST_ITEM_X) itemChoiceX = 40;
        else if(itemChoiceX == 40) itemChoiceX = SECOND_ITEM_X;
        else itemChoiceX = FIRST_ITEM_X;
      }
      //Right
      if(arduboy.justPressed(B_BUTTON)){
        if(playAudio)sound.tone(4000,100);
        if(itemChoiceX == FIRST_ITEM_X) itemChoiceX = SECOND_ITEM_X;
        else if(itemChoiceX == 40) itemChoiceX = FIRST_ITEM_X;
        else itemChoiceX = 40;
      }
      //Confirm. Replace the item in the selected slot.
      if(arduboy.justPressed(DOWN_BUTTON)){
        if(playAudio)sound.tone(4000,100);
        if(itemChoiceX == FIRST_ITEM_X){
          hero->item1 = rewardedItem;
          hero->item1Def = true;
        }else if(itemChoiceX == SECOND_ITEM_X){
          hero->item2 = rewardedItem;
          hero->item2Def = true;
        }
        updateAttack();
        sc = game;
      }
      break;

    case highscore:

      //Show the new highscore menu, it is basically a name selector with 3 characters
      printCentered(5, F("NEW HIGHSCORE!"));
      String highscore = String(gameRound) + "-" + String(level);
      printCentered(20, highscore);
      String letters = String(alphabet[letter1]) + String(alphabet[letter2]) + String(alphabet[letter3]);
      printCentered(35, letters);

      //Draw the indicator of the selections. Change the y position if the option is to confirm
      if(letterChoiceX == 37)
        arduboy.fillCircle(letterChoiceX, 53, 1);
      else
        arduboy.fillCircle(letterChoiceX, 32, 1);

      printCentered(50, "CONFIRM");
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

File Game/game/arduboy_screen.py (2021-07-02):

##This is a program to mirror the screen of the console
##To do so, in the game.ino file uncommment the serial lines
##and run this when the console is connected.
##Make sure the COM port is the correct one.

import serial
import pygame
import time

#Change COM port to the one used by the Arduino
ser = serial.Serial('COM8', 250000, timeout=0)
pygame.init()

# Set up the drawing window
screen = pygame.display.set_mode([1280, 640])
buffersize = int((128*64)/8);

x = 0
y = 0

white = (255,255,255)
black = (0,0,0)

elapsedTime = 0

# Run until the user asks to quit
running = True
while running:

    # Did the user click the window close button?
    for event in pygame.event.get():
        if event.type == pygame.QUIT:
            running = False

    #Update the screen shown if the serial is filled with the expected size
    if ser.in_waiting == buffersize:
        buffer = ser.read(buffersize);

        screen.fill(black)

        for b in buffer:
            for i in range(0, 9):
                if b >> i & 1 == 1:
                    pygame.draw.rect(screen, (255,255,255), pygame.Rect(x, y+i*10, 10, 10))
                    #screen.set_at((x, y + i), white)
            x+=10
            if(x == 1280):
                x = 0
                y += 80

        y = 0
        x = 0
        elapsedTime = time.time()*1000

        pygame.display.flip()
    

ser.close()

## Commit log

2021-03-29 classe buttons adicionada
2021-03-29 rev. 1 do pcb (em easyeda)
    [projeto_arduboy.kicad_pcb, projeto_arduboy.sch]
2021-04-30 fix branch
    [projeto_arduboy.kicad_pcb, projeto_arduboy.sch]
2021-07-02 Added pcb files
2021-09-10 alterçoes finais
    [Assembly.SLDASM, AssemblyV2 - Button-1.STL, AssemblyV2 - PartBottom-2.STL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]
2021-09-15 pptx para pdf
2023-02-25 repo structure
    [Assembly.SLDASM, AssemblyV2 - Button-1.STL, AssemblyV2 - PartBottom-2.STL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]
2023-02-25 include pcb files
